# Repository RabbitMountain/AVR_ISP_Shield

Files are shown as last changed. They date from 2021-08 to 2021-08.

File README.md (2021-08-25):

(Rabbit Mountain Research) AVR ISP Shield
========================

AVR ISP Shield

This shield, once assembled, gives your Arduino a 28-pin ZIF (Zero Insertion Force) socket so it can grab onto unsuspecting ICs. 
The socket and ISP headers are wired to work directly with the ArduinoISP code.

This is a slightly modified clone of the Evil Mad Scientist AVR ISP Shield v2.0. This version is built on the Sparkfun AVR ISP Shield Eagle files, but is more or less an exact clone of the Evil Mad Scientist Shield.

Rabbit Mountain Research changes
-------------------
* converted EvilMadScience design from gEDA to Autodesk EagleCAD
* fixed the non-working "hello" LED
* added 5v / 3v VCC power select jumper (taken from Sparkfun's ISP Shield design)
* added 0.1uF reset capacitor for UNO / 328p Arduino compatibility

Repository Contents
-------------------
* **/Hardware** - All Eagle design files (.brd, .sch)

License Information
-------------------
The hardware is released under [Creative Commons ShareAlike 4.0 International](https://creativecommons.org/licenses/by-sa/4.0/).
Sparkfun Electronics

&

Distributed under the [TAPR Open Hardware License](www.tapr.org/OHL).
Evil Mad Science LCC

Distributed as-is; no warranty is given.

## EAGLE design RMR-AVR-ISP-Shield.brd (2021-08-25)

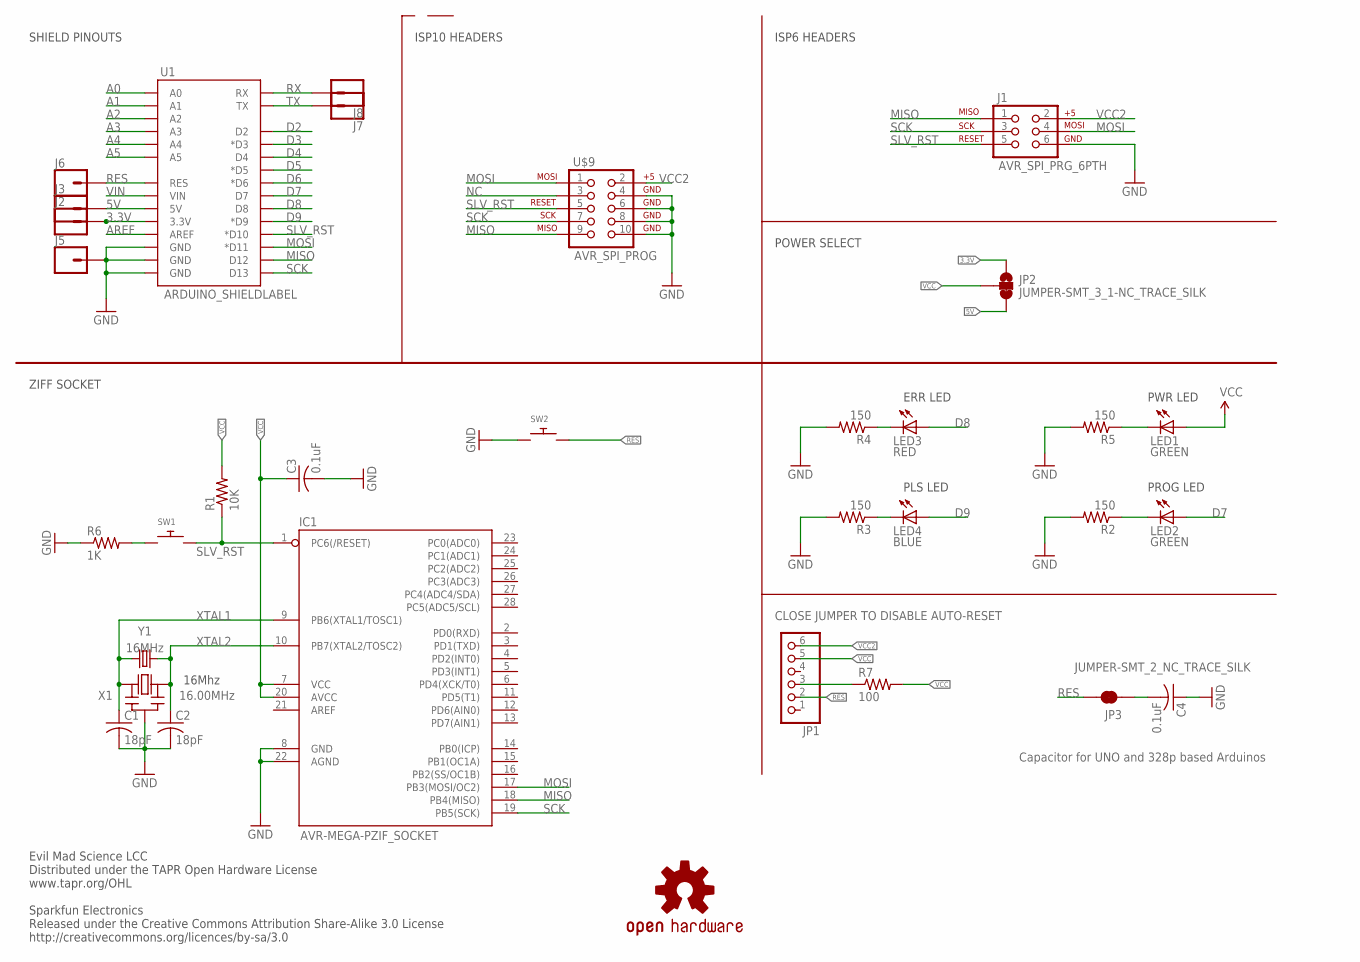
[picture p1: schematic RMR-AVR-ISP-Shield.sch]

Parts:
C1, C2: 18pF; C025-024X044
C3, C4: 0.1uF; C025-024X044
IC1: AVR-MEGA-PZIF_SOCKET; DIL28-3-ZIF_SOCKET
J1: AVR_SPI_PRG_6PTH; 2X3
J2, J3, J5, J6, J7, J8: CONN_01; 1X01
JP1: PINHD-1X6/90; 1X06/90
JP2: JUMPER-SMT_3_1-NC_TRACE_SILK; SMT-JUMPER_3_1-NC_TRACE_SILK
JP3: JUMPER-SMT_2_NC_TRACE_SILK; SMT-JUMPER_2_NC_TRACE_SILK
LED1, LED2: GREEN; LED3MM
LED3: RED; LED3MM
LED4: BLUE; LED3MM
R1: 10K; AXIAL-0.4
R2, R3, R4, R5: 150; AXIAL-0.4
R6: 1K; AXIAL-0.4
R7: 100; AXIAL-0.4
SW1, SW2: SWITCH_PUSHBUTTONEVQ-PE; TACT_PANA-EVQ
U1: ARDUINO_SHIELDLABEL; DUEMILANOVE_SHIELD
U$4: OSHW-LOGOM; OSHW-LOGO-M
U$9: AVR_SPI_PROG; AVR_ICSP
X1: 16.00MHz; CERM_OSC
Y1: 16MHz; HC49US

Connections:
3.3V: J2.1, JP2.1, U1.3.3V
5V: J3.1, JP2.3, U1.5V
A0: U1.A0
A1: U1.A1
A2: U1.A2
A3: U1.A3
A4: U1.A4
A5: U1.A5
AREF: U1.AREF
D2: U1.D2
D3: U1.D3 (*D3)
D4: U1.D4
D5: U1.D5 (*D5)
D6: U1.D6 (*D6)
D7: LED2.A, U1.D7
D8: LED3.A, U1.D8
D9: LED4.A, U1.D9 (*D9)
GND: C1.2, C2.2, C3.2, C4.1, IC1.8 (GND), IC1.22 (AGND), J1.6, J5.1, R2.P$2 (2), R3.P$2 (2), R4.P$2 (2), R5.P$2 (2), R6.P$1 (1), SW2.P$1, U1.GND@0 (GND), U1.GND@1 (GND), U1.GND@2 (GND), U$9.4, U$9.6, U$9.8, U$9.10, X1.P$2 (GND)
MISO: IC1.18 (PB4(MISO)), J1.1, U1.D12, U$9.9
MOSI: IC1.17 (PB3(MOSI/OC2)), J1.4, U1.D11 (*D11), U$9.1
unnamed: R6.P$2 (2), SW1.P$1
unnamed: LED2.K (C), R2.P$1 (1)
unnamed: LED3.K (C), R4.P$1 (1)
unnamed: LED1.K (C), R5.P$1 (1)
unnamed: JP1.3, R7.P$1 (1)
unnamed: LED4.K (C), R3.P$1 (1)
unnamed: C4.2, JP3.1
NC: U$9.3
RES: J6.1, JP1.2, JP3.2, SW2.P$2, U1.RES
RX: J8.1, U1.RX
SCK: IC1.19 (PB5(SCK)), J1.3, U1.D13, U$9.7
SLV_RST: IC1.1 (PC6(/RESET)), J1.5, R1.P$1 (1), SW1.P$2, U1.D10 (*D10), U$9.5
TX: J7.1, U1.TX
VCC: C3.1, IC1.7 (VCC), IC1.20 (AVCC), JP1.5, JP2.2, LED1.A, R1.P$2 (2), R7.P$2 (2)
VCC2: J1.2, JP1.6, U$9.2
VIN: U1.VIN
XTAL1: C1.1, IC1.9 (PB6(XTAL1/TOSC1)), X1.P$1 (IN), Y1.1
XTAL2: C2.1, IC1.10 (PB7(XTAL2/TOSC2)), X1.P$3 (OUT), Y1.2

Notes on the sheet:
PWR LED
PROG LED
ISP6 HEADERS
ERR LED
PLS LED
16Mhz
Evil Mad Science LCC Distributed under the TAPR Open Hardware License www.tapr.org/OHL Sparkfun Electronics Released under the Creative Commons Attribution Share-Alike 3.0 License http://creativecommons.org/licences/by-sa/3.0
ZIFF SOCKET
SHIELD PINOUTS
ISP10 HEADERS
CLOSE JUMPER TO DISABLE AUTO-RESET
POWER SELECT
Capacitor for UNO and 328p based Arduinos

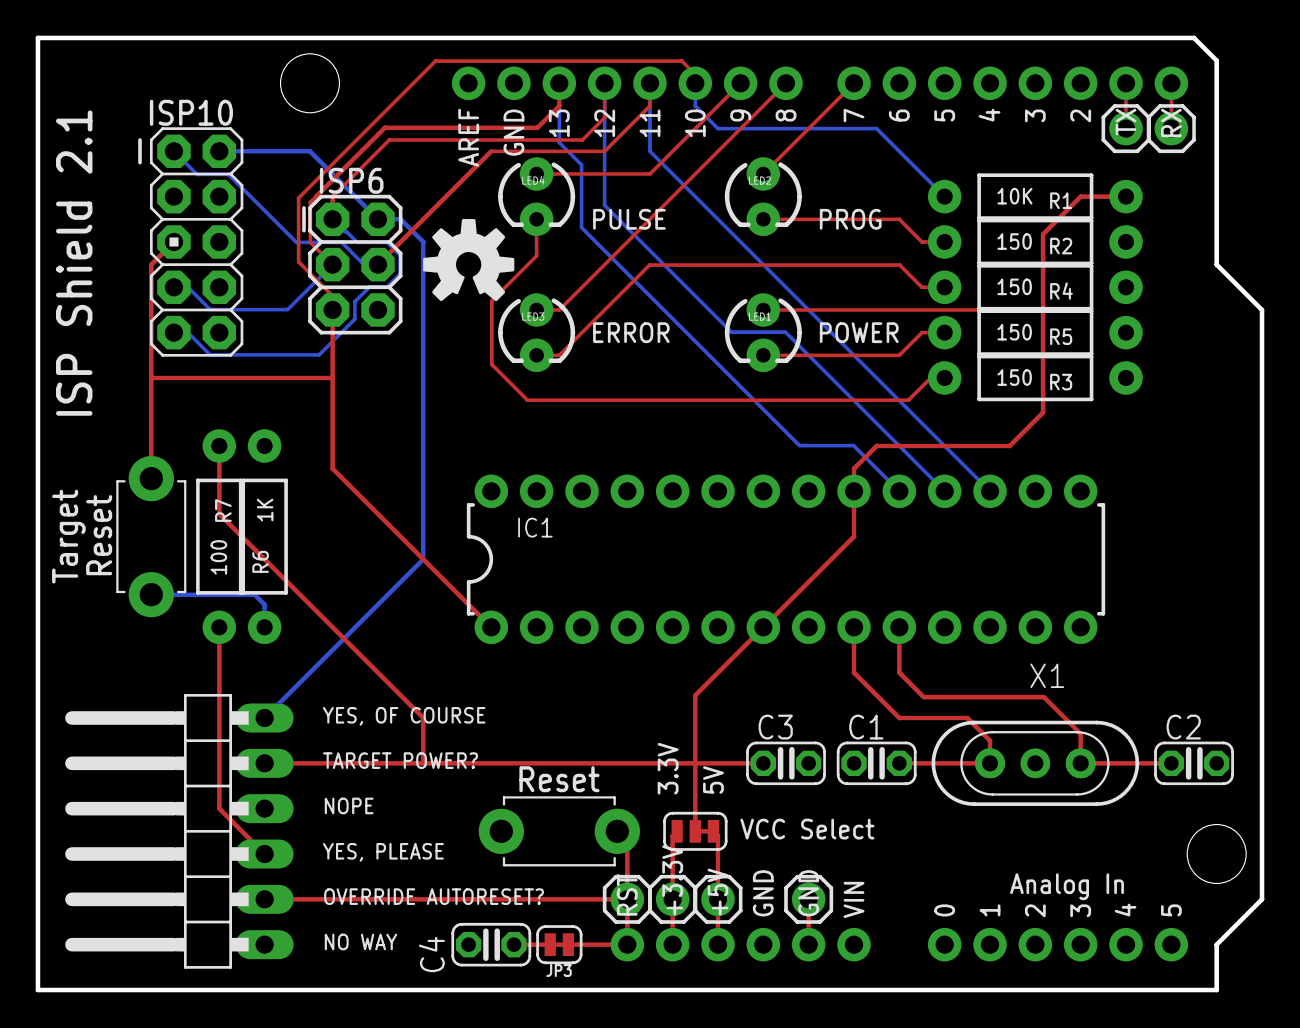
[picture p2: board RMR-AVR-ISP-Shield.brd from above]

Board: 2 copper layers, 68.6 x 53.3 mm, 33 parts (0 on the bottom side), 24 nets.

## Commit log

2021-08-24 Add files via upload
    changed reset capacitor
    [RMR-AVR-ISP-Shield.brd, RMR-AVR-ISP-Shield.sch]
2021-08-25 Add files via upload
    added jumper to the reset capacitor for UNO / 328p based Arduinos.
    [RMR-AVR-ISP-Shield.brd, RMR-AVR-ISP-Shield.sch]

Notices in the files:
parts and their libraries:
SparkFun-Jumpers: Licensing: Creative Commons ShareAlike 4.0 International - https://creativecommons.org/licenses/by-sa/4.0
